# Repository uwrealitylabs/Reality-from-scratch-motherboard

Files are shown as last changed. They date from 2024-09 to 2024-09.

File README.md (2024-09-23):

# Reality From Scratch Motherboard

### RP2040+ICM42688 board made by Vincent Xie (@icanc)

> [!CAUTION]
> This board has not been tested to function properly

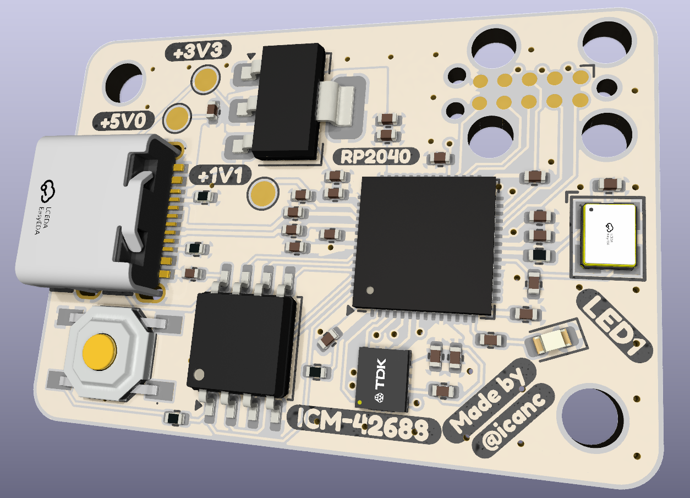
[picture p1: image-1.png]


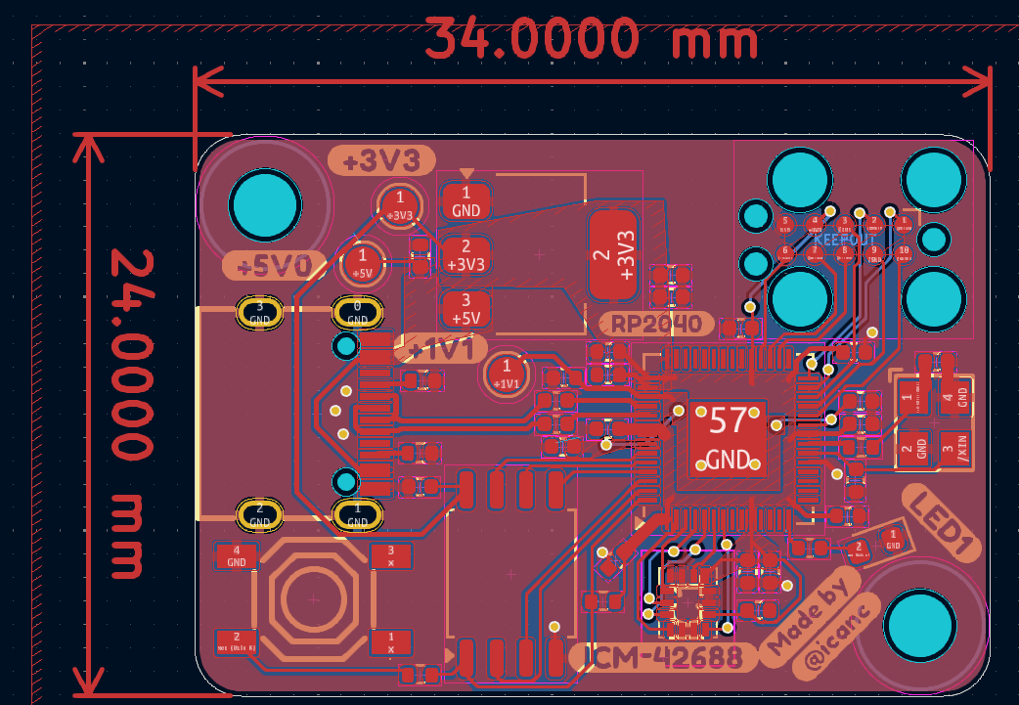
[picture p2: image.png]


Features:
- ICM-42688 over SPI
- TC2050 connector for debugging and GPIO testing
- LEDs for status

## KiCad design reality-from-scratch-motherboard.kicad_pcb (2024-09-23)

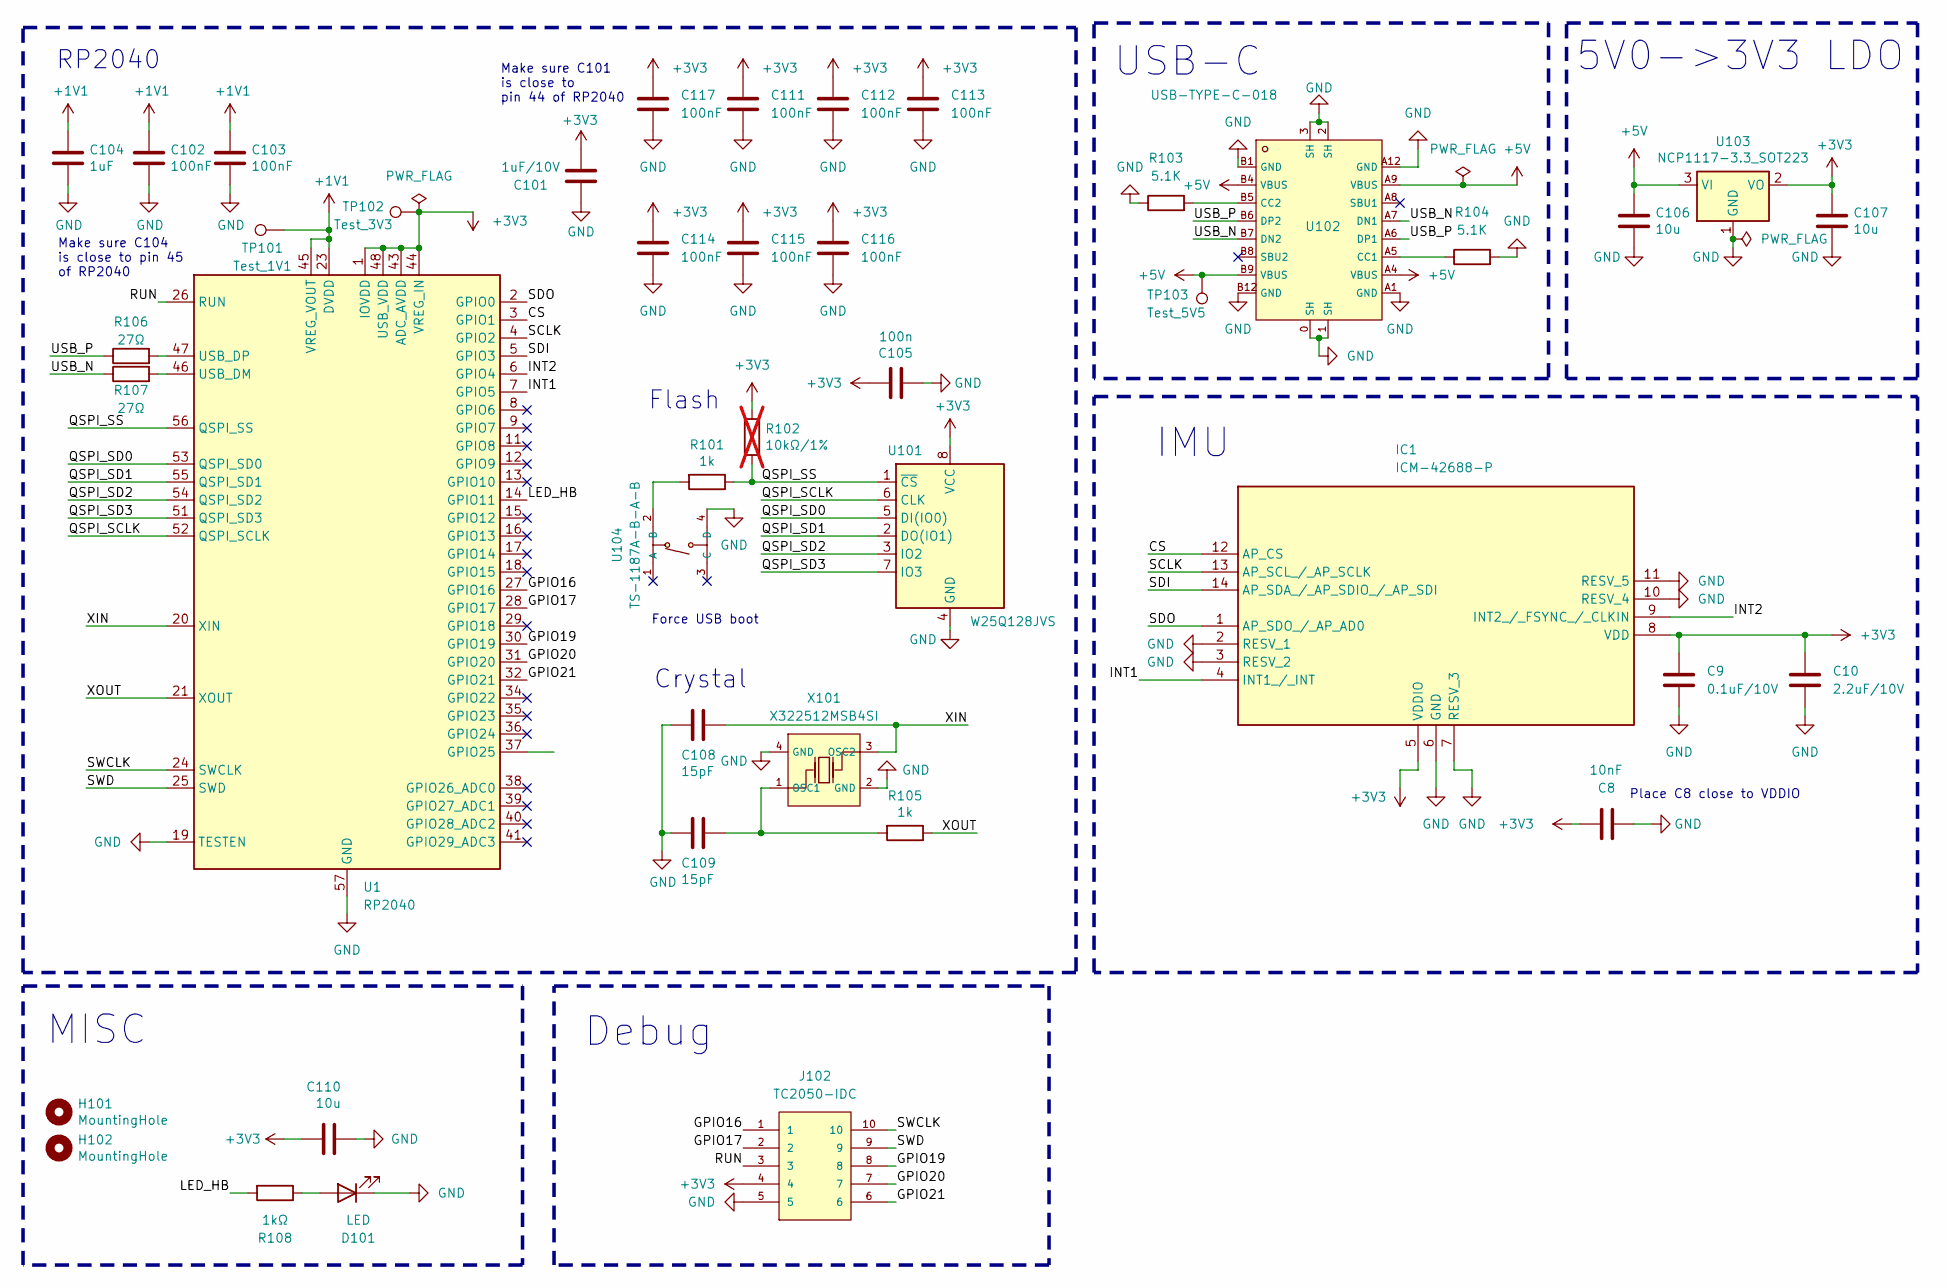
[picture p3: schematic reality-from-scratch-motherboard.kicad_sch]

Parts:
C8: 10nF; C_0402_1005Metric
C9: 0.1uF/10V; C_0402_1005Metric
C10: 2.2uF/10V; C_0402_1005Metric
C101: 1uF/10V; C_0402_1005Metric
C102, C103, C111, C112, C113, C114, C115, C116, C117: 100nF; C_0402_1005Metric
C104: 1uF; C_0402_1005Metric
C105: 100n; C_0402_1005Metric
C106, C107, C110: 10u; C_0402_1005Metric
C108, C109: 15pF; C_0402_1005Metric
D101: LED; LED_0603_1608Metric
H101, H102: MountingHole; MountingHole_2.7mm_M2.5
IC1: ICM-42688-P; IIM42352; Manufacturer_Part_Number ICM-42688-P; Mouser Part Number 410-ICM-42688-P
J102: TC2050-IDC; Tag-Connect_TC2050-IDC-FP_2x05_P1.27mm_Vertical; PARTREV A
R101, R105: 1k; R_0402_1005Metric
R102: 10kΩ/1%; R_0402_1005Metric; not fitted
R103, R104: 5.1K; R_0402_1005Metric
R106, R107: 27Ω; C_0402_1005Metric
R108: 1kΩ; C_0402_1005Metric
TP101: Test_1V1; TestPoint_Pad_D1.5mm
TP102: Test_3V3; TestPoint_Pad_D1.5mm
TP103: Test_5V5; TestPoint_Pad_D1.5mm
U1: RP2040; QFN-56-1EP_7x7mm_P0.4mm_EP3.2x3.2mm
U101: W25Q128JVS; SOIC-8_5.23x5.23mm_P1.27mm
U102: USB-TYPE-C-018; USB-C_SMD-TYPE-C-31-M-12; LCSC C2927038
U103: NCP1117-3.3_SOT223; SOT-223-3_TabPin2
U104: TS-1187A-B-A-B; SW-SMD_4P-L5.1-W5.1-P3.70-LS6.5-TL-2; LCSC C318884
X101: X322512MSB4SI; OSC-SMD_4P-L3.2-W2.5-BL; LCSC C9002

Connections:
+1V1: C102.1, C103.1, C104.1, TP101.1, U1.23 (DVDD), U1.45 (VREG_VOUT), U1.50 (DVDD)
+3V3: C8.1, C9.1, C10.1, C101.1, C105.1, C107.1, C110.1, C111.1, C112.1, C113.1, C114.1, C115.1, C116.1, C117.1, IC1.5 (VDDIO), IC1.8 (VDD), J102.4, R102.1, TP102.1, U1.1 (IOVDD), U1.10 (IOVDD), U1.22 (IOVDD), U1.33 (IOVDD), U1.42 (IOVDD), U1.43 (ADC_AVDD), U1.44 (VREG_IN), U1.48 (USB_VDD), U1.49 (IOVDD), U101.8 (VCC), U103.2 (VO)
+5V: C106.1, TP103.1, U102.A4 (VBUS), U102.A9 (VBUS), U102.B4 (VBUS), U102.B9 (VBUS), U103.3 (VI)
/CS: IC1.12 (AP_CS), U1.3 (GPIO1)
/GPIO16: J102.1, U1.27 (GPIO16)
/GPIO17: J102.2, U1.28 (GPIO17)
/GPIO19: J102.8, U1.30 (GPIO19)
/GPIO20: J102.7, U1.31 (GPIO20)
/GPIO21: J102.6, U1.32 (GPIO21)
/INT1: IC1.4 (INT1_/_INT), U1.7 (GPIO5)
/INT2: IC1.9 (INT2_/_FSYNC_/_CLKIN), U1.6 (GPIO4)
/LED_HB: R108.2, U1.14 (GPIO11)
/QSPI_SCLK: U1.52 (QSPI_SCLK), U101.6 (CLK)
/QSPI_SD0: U1.53 (QSPI_SD0), U101.5 (DI(IO0))
/QSPI_SD1: U1.55 (QSPI_SD1), U101.2 (DO(IO1))
/QSPI_SD2: U1.54 (QSPI_SD2), U101.3 (IO2)
/QSPI_SD3: U1.51 (QSPI_SD3), U101.7 (IO3)
/QSPI_SS: R101.1, R102.2, U1.56 (QSPI_SS), U101.1 (~CS)
/RUN: J102.3, U1.26 (RUN)
/SCLK: IC1.13 (AP_SCL_/_AP_SCLK), U1.4 (GPIO2)
/SDI: IC1.14 (AP_SDA_/_AP_SDIO_/_AP_SDI), U1.5 (GPIO3)
/SDO: IC1.1 (AP_SDO_/_AP_AD0), U1.2 (GPIO0)
/SWCLK: J102.10, U1.24 (SWCLK)
/SWD: J102.9, U1.25 (SWD)
/USB_N: R107.1, U102.A7 (DN1), U102.B7 (DN2)
/USB_P: R106.1, U102.A6 (DP1), U102.B6 (DP2)
/XIN: C108.1, U1.20 (XIN), X101.3 (OSC2)
/XOUT: R105.1, U1.21 (XOUT)
GND: C8.2, C9.2, C10.2, C101.2, C102.2, C103.2, C104.2, C105.2, C106.2, C107.2, C108.2, C109.2, C110.2, C111.2, C112.2, C113.2, C114.2, C115.2, C116.2, C117.2, D101.1 (K), IC1.2 (RESV_1), IC1.3 (RESV_2), IC1.6 (GND), IC1.7 (RESV_3), IC1.10 (RESV_4), IC1.11 (RESV_5), J102.5, R103.1, R104.2, U1.19 (TESTEN), U1.57 (GND), U101.4 (GND), U102.0 (SH), U102.1 (SH), U102.2 (SH), U102.3 (SH), U102.A1 (GND), U102.A12 (GND), U102.B1 (GND), U102.B12 (GND), U103.1 (GND), U104.4 (D), X101.2 (GND), X101.4 (GND)
unnamed: D101.2 (A), R108.1
unnamed: R107.2, U1.46 (USB_DM)
unnamed: R106.2, U1.47 (USB_DP)
unnamed: R104.1, U102.A5 (CC1)
unnamed: R103.2, U102.B5 (CC2)
unnamed: R101.2, U104.2 (B)
unnamed: C109.1, R105.2, X101.1 (OSC1)

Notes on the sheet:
Crystal
RP2040
Make sure C101 is close to pin 44 of RP2040
5V0->3V3 LDO
Make sure C104 is close to pin 45 of RP2040
MISC
USB-C
Place C8 close to VDDIO
Debug
Flash
IMU
Force USB boot

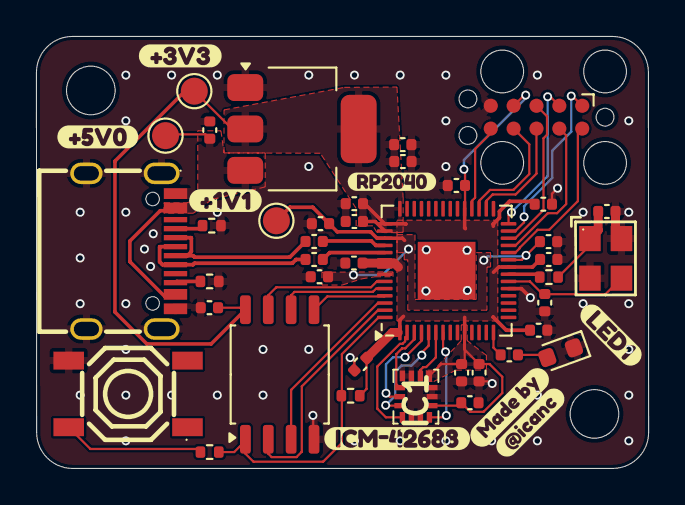
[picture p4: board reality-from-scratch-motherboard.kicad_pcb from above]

Board: 2 copper layers, 34.0 x 24.0 mm, 50 parts (0 on the bottom side), 36 nets.

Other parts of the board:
kibuzzard-66F14AE0: G***; kibuzzard-66F14AE0
kibuzzard-66F14B1E: G***; kibuzzard-66F14B1E
kibuzzard-66F14B33: G***; kibuzzard-66F14B33
kibuzzard-66F144BA: G***; kibuzzard-66F144BA
kibuzzard-66F1440E: G***; kibuzzard-66F1440E
kibuzzard-66F14516: G***; kibuzzard-66F14516
kibuzzard-66F14520: G***; kibuzzard-66F14520
kibuzzard-66F14561: G***; kibuzzard-66F14561

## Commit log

2024-08-29 added submodule library
    [reality-from-scratch-motherboard.kicad_pcb, reality-from-scratch-motherboard.kicad_sch]
2024-08-29 basic design done
    [reality-from-scratch-motherboard.kicad_sch]
2024-09-22 schematics first revision done
    [reality-from-scratch-motherboard.kicad_sch]
2024-09-23 fixed MD file
    [reality-from-scratch-motherboard.kicad_pcb, reality-from-scratch-motherboard.kicad_sch]
